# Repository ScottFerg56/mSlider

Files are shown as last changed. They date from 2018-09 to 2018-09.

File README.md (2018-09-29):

Slider Photo

# mSlider
**mSlider** ('m' for 'micro') is an Arduino implementation for a DIY automated camera slider, including pan and intervalometer functions.

This project includes software and [plans](https://github.com/ScottFerg56/mSlider/tree/master/Plans) with a parts list and STL files for 3D printing some parts. The implementation, as provided, is for an [**Adafruit Feather M0 Bluefruit LE**](https://learn.adafruit.com/adafruit-feather-m0-bluefruit-le?view=all) Arduino-compatible processor but may be adapted for other suitably capable Arduino processors. The Arduino software implementation is provided
 as a [Visual Studio](https://visualstudio.microsoft.com/free-developer-offers/) solution using the [Visual Micro](https://www.visualmicro.com/) extension. There are free versions of these tools available. They are highly recommended as significantly more powerful than the Arduino IDE. The source files can probably also be built using the Arduino IDE, but no support is provided for using other tools.

The [**Slider gallery**](https://www.forestmoon.com/Piwigo/index.php?/category/Slider) Shows lots of construction and overview information with details in the captions. 

This project requires other reusable libraries found in the **mLibs** companion project:
* **Applet** - A uniform mechanism for organizing and communicating with hardware components
* **FMBlue** - An Applet for Bluetooth LE interfacing.
* **FMDebug** - An Applet for Serial interfacing and debugging enhancements.
* **FMIvalometer** - An Applet implementing the Intervalometer hardware functions.
* **FMStepper** - A generic Stepper Motor control Applet used to control the Slide and Pan functions.
* **FMTime** - A class to provide date/time functionality.
* **Metronome** - A simple class to provide polled Timer functions.

Place the mSlider and mLibs projects in sibling subdirectories in your file system to insure proper compilation.

The mSlider project has dependencies on several libraries, including the Arduino libraries of course:
* [**Adafruit nRF51 BLE Library**](https://learn.adafruit.com/adafruit-feather-32u4-bluefruit-le/installing-ble-library)
* [**AccelStepper library**](http://www.airspayce.com/mikem/arduino/AccelStepper/) - Required by the FMStepper Applet.

The **mSlider** application communicates via Bluetooth LE with a controlling application implemented in the **Slider** companion project. **Slider** provides both Arduino and Windows Universal Windows Platform (UWP) implementations for controlling the Camera Slider hardare.

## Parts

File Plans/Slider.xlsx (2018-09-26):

Description | Part # | Price | Qty | Subtotal | Notes | Supplier
1/4"-20 Round Screw Plate | 545468 | $3.99 | 1 | $3.99 | bottom plate of pan head to mount on mini ball head | https://www.servocity.com/0-250-20-round-screw-plate
0.500" Length, 1/4" OD Aluminum Spacers for #6 Screw Size (0.140” ID) | 633166 | $1.39 | 4 | $5.56 | spacers mount between screw plate and pillow block | https://www.servocity.com/1-4-od-aluminum-spacers-for-6-screw-size-0-140-id
1/4" Bore Side Tapped Pillow Block | 535130 | $6.49 | 2 | $12.98 | pillow blocks for each end of the channel hold the shaft | https://www.servocity.com/250-bore-quad-pillow-block
1.50” Aluminum Channel | 585440 | $2.99 | 1 | $2.99 | the channel is the main body of the pan head | https://www.servocity.com/1-50-channel
Flat 0.770" Pattern Bracket C | 585586 | $1.99 | 1 | $1.99 | mounts pan stepper gear and main gear with proper spacing | https://www.servocity.com/flat-bracket-c
1/4" Stainless Steel Precision Shafting Length 3.00" | 634162 | $1.19 | 1 | $1.19 | one end to be threaded to 1/4-20 as camera mount | https://www.servocity.com/0-250-1-4-stainless-steel-precision-shafting
0.770" Pattern Set Screw Hubs Bore 0.250" | 545548 | $4.99 | 1 | $4.99 | hub mounts the big main gear to the shaft | https://www.servocity.com/770-set-screw-hubs
32 Pitch Acetyl Hub Mount Spur Gears (1/8" Face) # of teeth 80T | RHA32-26-80 | $6.60 | 1 | $6.60 | big main gear that the camera sits on, meshes with drive gear | https://www.servocity.com/32p-acetyl-hub-mount-spur-gears-0-125-face
5mm Bore 32 Pitch, 16T Shaft Mount Pinion Gear | 615342 | $7.99 | 1 | $7.99 | drive gear fits on the pan stepper shaft with set screw | https://www.servocity.com/5mm-bore-32p-16t-shaft-mount-pinion-gears
NEMA 17 Stepper Motor Mount | 555152 | $7.49 | 1 | $7.49 | mounts the stepper motor to the pattern bracket | https://www.servocity.com/nema-17-stepper-motor-mount
Stepper Motor 1.8 degree step angle 12V 5mm Drive Shaft |  | $14.95 | 2 | $29.90 | stepper motors for slide and pan drive | https://www.sparkfun.com/products/9238
Micro Switch |  | $2.00 | 1 | $2.00 | limit switch for slide | https://vetco.net/
Lunies Mini Ball Head 2Pcs |  | $8.99 | 1 | $8.99 | ball head mounts on slide table and holds pan head | https://www.amazon.com/gp/product/B06XJRRKJT
Neewer 6-In-1 Timer Shutter Release |  | $23.99 | 1 | $23.99 | cannibalized for shutter cable and adapters for 6 camera brands | https://www.amazon.com/gp/product/B01FFFDX6C
Neewer Aluminum Alloy Camera Track Slider (80 cm) |  | $61.94 | 1 | $61.94 | manual slider forms the base of our automatic slider | https://www.amazon.com/Neewer-Stabilizer-Camcorder-Photography-kilograms/dp/B06Y46H989/
GT2 10 Meters Timing Belt + 2Pcs Bore 5mm 20Teeth Timing Pulley Wheel |  | $10.98 | 1 | $10.98 | timing belt and pulleys to drive the slide table | https://www.amazon.com/dp/B01GTGOD6U
3/8" Split Wire Loom Tubing (Polyethylene) - 10FT - Black |  | $8.51 | 1 | $8.51 | about 5" used to wrap slide motor wires | https://www.amazon.com/Split-Wire-Loom-Tubing-Polyethylene/dp/B00S1PPHM2
50ft-1/4" PET Expandable Braided Sleeving –Black |  | $5.99 | 1 | $5.99 | about 30" used to wrap pan motor wires and shutter cable | https://www.amazon.com/Wang-Data-Expandable-Sleeving-management-organizer/dp/B074M2Y3G1
Hammond 1455C801BK Enclosure |  | $14.10 | 1 | $14.10 | enclosure for all the electronics | https://www.mouser.com/ProductDetail/Hammond-Manufacturing/1455C801BK
Big Easy Stepper Motor Driver |  | $19.95 | 2 | $39.90 | one each for the slide and pan motors | https://www.sparkfun.com/products/12859
Adafruit Feather M0 Bluefruit LE |  | $29.95 | 1 | $29.95 | control processor with Bluetooth LE interface | https://www.adafruit.com/product/2995
Socket Contact Gold 22-24 AWG Crimp |  | $0.16 | 10 | $1.58 | contact for the 4- and 2- position connector receptacles | https://www.digikey.com/product-detail/en/molex-llc/0016020103/WM2512-ND/115063
4 Position Rectangular Housing Connector Receptacle Black 0.100" |  | $0.27 | 2 | $0.54 | plugs for slide and pan stepper motor connections | https://www.digikey.com/product-detail/en/molex-llc/0050579404/WM2902-ND/115057
Connector Header Through Hole 4 position 0.100" |  | $1.01 | 2 | $2.02 | sockets for slide and pan stepper motor connections | https://www.digikey.com/product-detail/en/molex-llc/0701070003/WM2535-ND/210970
2 Position Rectangular Housing Connector Receptacle Black 0.100" |  | $0.26 | 1 | $0.26 | plug for limit switch connection | https://www.digikey.com/product-detail/en/molex-llc/50-57-9402/WM2900-ND/115029
Connector Header Through Hole 2 position 0.100" |  | $0.80 | 1 | $0.80 | socket for limit switch connection | https://www.digikey.com/product-detail/en/molex-llc/0705430036/WM4824-ND/313739
Power Barrel Connector Jack 2.10mm ID (0.083"), 5.50mm OD (0.217") Panel Mount |  | $0.64 | 1 | $0.64 | power connector (using 12V supply) | https://www.digikey.com/product-detail/en/cui-inc/PJ-010A/CP-010A-ND/1644501
Linear Voltage Regulator IC Output 5V 1.5A TO-220AB |  | $0.50 | 1 | $0.50 | regulator to get 5V from 12V supply | https://www.digikey.com/product-detail/en/stmicroelectronics/L7805CV/497-1443-5-ND/585964
 |  |  |  | $298.36 | Total
6-32 x 0.375" (3/8) Flat Head Phillips Machine Screw |  |  | 8 |  | connect pattern bracket to upper pillow block and stepper mount
6-32 x 0.3125" (5/16) Zinc-Plated Socket Head Machine Screw (25 pack) |  |  | 4 |  | connect pillow blocks to channel
6-32 x 0.875" (7/8) Zinc-Plated Socket Head Machine Screw |  |  | 4 |  | connect screw plate to lower pillow block
10-32 x 1" Flat Head Phillips Machine Screw |  |  | 4 |  | connect slide stepper and mounting plate to slider base
Aluminum Spacer 1/4 OD x .192 ID x 5/8" Long for #10 screw size |  |  | 4 |  | connect slide stepper and mounting plate to slider base
Camera Pad - affix to 80T gear for camera cushion |  |  |  |  | CameraPad.STL - 3D printed in flexible plastic filament
Mounting Plate for Big Easy Drivers inside enclosure |  |  |  |  | DriverMount.STL
Mounting Plate for Feather processor and connectors inside enclosure |  |  |  |  | FeatherMout.STL
Mounting Tab for limit switch onto slide drive stepper motor |  |  |  |  | LimitMount.STL
Enclosure end plate with holes for USB and Pan motor connectors |  |  |  |  | PlateLeft.STL
Enclosure end plate with holes for Slide motor, limit switch and power connectors |  |  |  |  | PlateRight.STL
Anchor the timing belt to the slide table |  |  |  |  | BeltAnchor.STL
Plate for mounting slide drive stepper motor to the slide rail base |  |  |  |  | StepperMount.STL

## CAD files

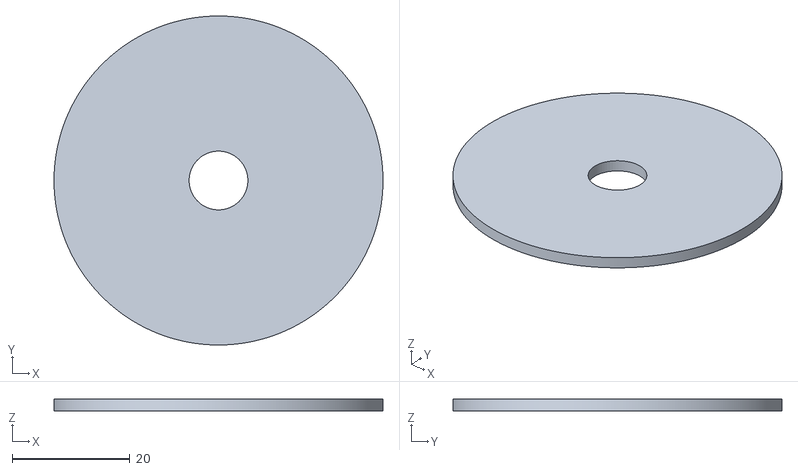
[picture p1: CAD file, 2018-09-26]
Plans/models/CameraPad.STL
56.0 x 56.0 x 2.00

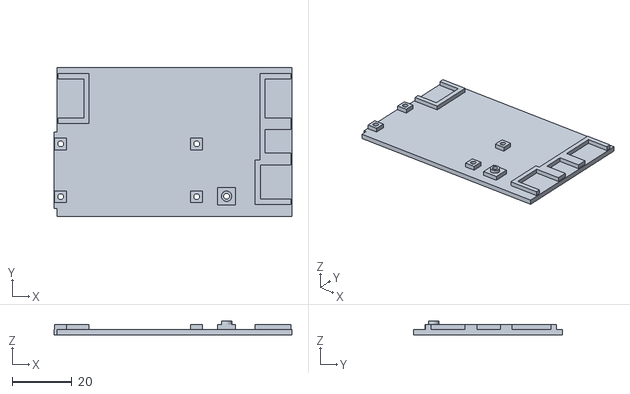
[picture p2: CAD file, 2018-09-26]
Plans/models/FeatherMount.STL
80.0 x 50.0 x 4.60

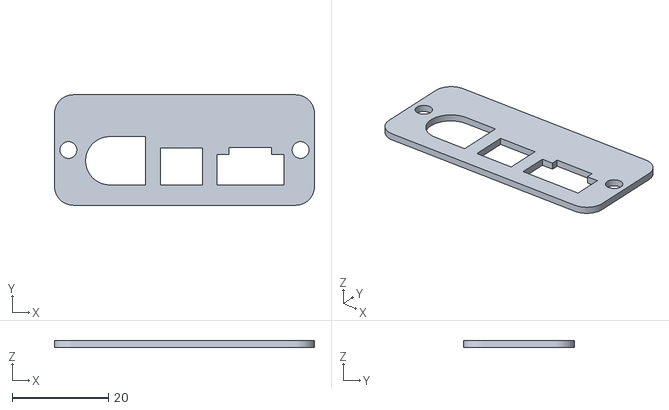
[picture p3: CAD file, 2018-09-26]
Plans/models/PlateRight.STL
53.9 x 22.9 x 1.40

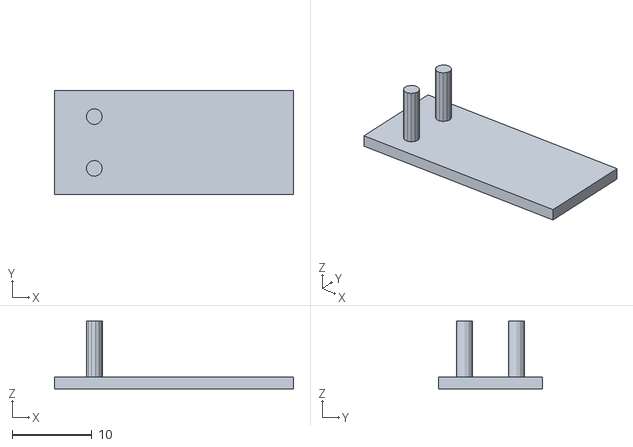
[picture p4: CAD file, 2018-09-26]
Plans/models/LimitMount.STL
30.0 x 13.0 x 8.50

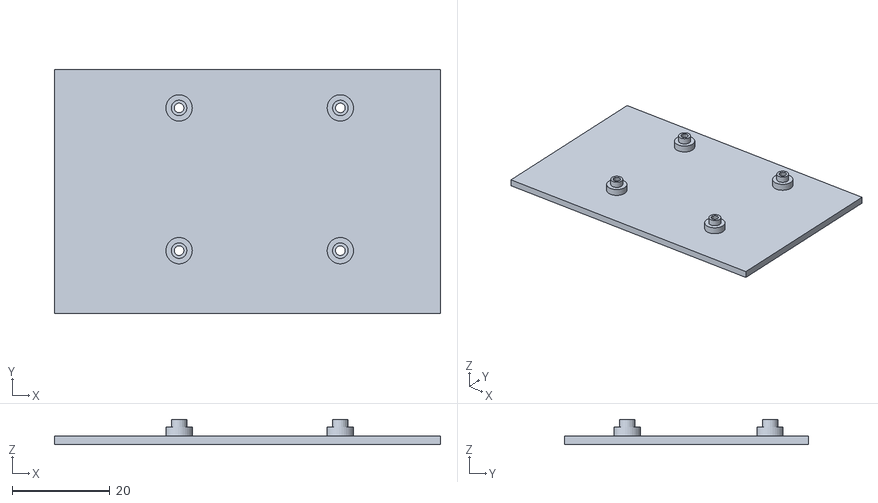
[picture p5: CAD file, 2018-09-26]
Plans/models/DriverMount.STL
79.0 x 50.0 x 5.20

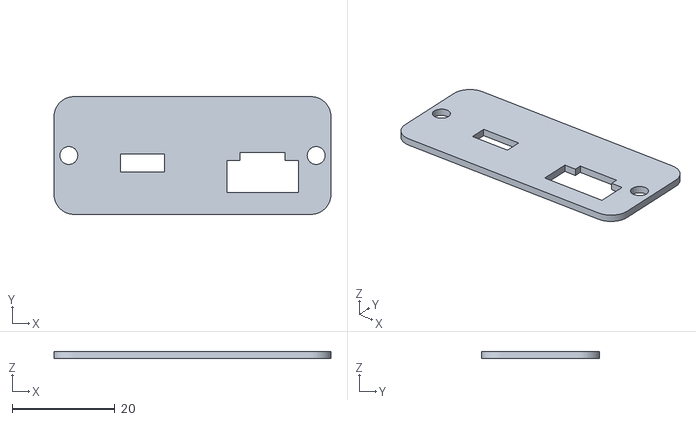
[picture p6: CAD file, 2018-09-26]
Plans/models/PlateLeft.STL
53.9 x 22.9 x 1.40

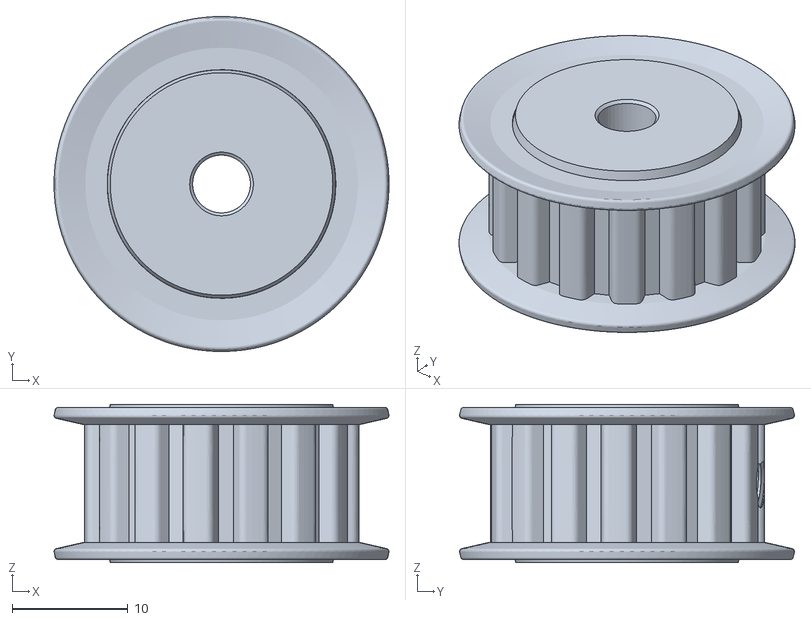
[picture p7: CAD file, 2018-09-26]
Plans/models/BeltAnchor.stl
28.9 x 29.0 x 13.7

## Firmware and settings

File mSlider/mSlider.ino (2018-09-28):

/*

         OOOOO    OOO      OO      OOO
        OO   OO    OO      OO       OO
        OO   OO    OO               OO
OOO OO   OO        OO     OOO     OOOO   OOOOO  OO OOO
OOOOOOO   OOO      OO      OO    OO OO  OO   OO  OO  OO
OO O OO     OO     OO      OO   OO  OO  OOOOOOO  OO  OO
OO O OO OO   OO    OO      OO   OO  OO  OO       OO
OO O OO OO   OO    OO      OO   OO  OO  OO   OO  OO
OO   OO  OOOOO    OOOO    OOOO   OOO OO  OOOOO  OOOO

    (c) 2018 Scott Ferguson
    This code is licensed under MIT license (see LICENSE file for details)

    An Arduino implementation for a DIY automated camera slider, including pan and intervalometer functions.
    For more information, visit: https://github.com/ScottFerg56/mSlider/tree/master.
*/

#include "mSlider.h"
#include <FMBlue.h>
#include <FMStepper.h>
#include <FMIvalometer.h>
#include "Global.h"

App	myApp;

void setup()
{
	// include the date & time of compilation in our connection banner
	fmDebug.Init("Slider Controller\r\n" __DATE__ " " __TIME__, false, LEDpin);
	// suppress debug output when we're not heavily into debugging
//	fmDebug.Quiet = true;
	// add the debug Applet
	myApp.AddApplet(&fmDebug);

	// add the stepper Applet that controls the Slider
	AccelStepper* stepper = new AccelStepper(AccelStepper::DRIVER, SlideStep_Pin, SlideDir_Pin);
	FMStepper* fmstepper = new FMStepper('s', 80.0, stepper, SlideLimit_Pin);
	stepper->setPinsInverted(true);
	fmstepper->SetSpeedLimit(50);
	fmstepper->SetMaxSpeed(30);
	fmstepper->SetAcceleration(25);
	fmstepper->SetLimits(0, 640);
	fmstepper->Name = "Slide";
	myApp.AddApplet(fmstepper);

	// add the stepper Applet that controls the Pan
	stepper = new AccelStepper(AccelStepper::DRIVER, PanStep_Pin, PanDir_Pin);
	fmstepper = new FMStepper('p', 400.0 / 9, stepper);
	fmstepper->SetSpeedLimit(90);
	fmstepper->SetMaxSpeed(55);
	fmstepper->SetAcceleration(45);
	fmstepper->SetLimits(-360, 360);
	fmstepper->Name = "Pan";
	myApp.AddApplet(fmstepper);

	FMIvalometer* ivalometer = new FMIvalometer('i', Focus_Pin, Shutter_Pin);
	ivalometer->Name = "Intervalometer";
	myApp.AddApplet(ivalometer);

	myApp.AddApplet(new Global('g'));

	// add the Bluetooth interface Applet
	myApp.OutputApplet = new FMBlue('b', "SLIDER");
	myApp.AddApplet(myApp.OutputApplet);
}

void loop()
{
	// invoke Run on all the Applets
	myApp.Run();
}

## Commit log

2018-08-08 support app request for stepper position
2018-08-14 Add camera shutter control
2018-09-05 interface camera properties
2018-09-05 Milestone: Slide, Pan and Camera all functional!
2018-09-24 centralize property mechanism in Applet class separate Stepper/Global/Intervalometer Applets integrate ScaledStepper into FMStepper applet
2018-09-25 major changes for String usage separate FMDebug applet from debug.print using Print class
2018-09-26 add parts list and STL models
    [BeltAnchor.stl, CameraPad.STL, DriverMount.STL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]
